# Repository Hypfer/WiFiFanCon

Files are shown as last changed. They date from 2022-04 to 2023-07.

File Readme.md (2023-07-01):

# WiFiFanCon

Control 12V PC Fans via Wi-Fi and [Tasmota](https://github.com/arendst/Tasmota)

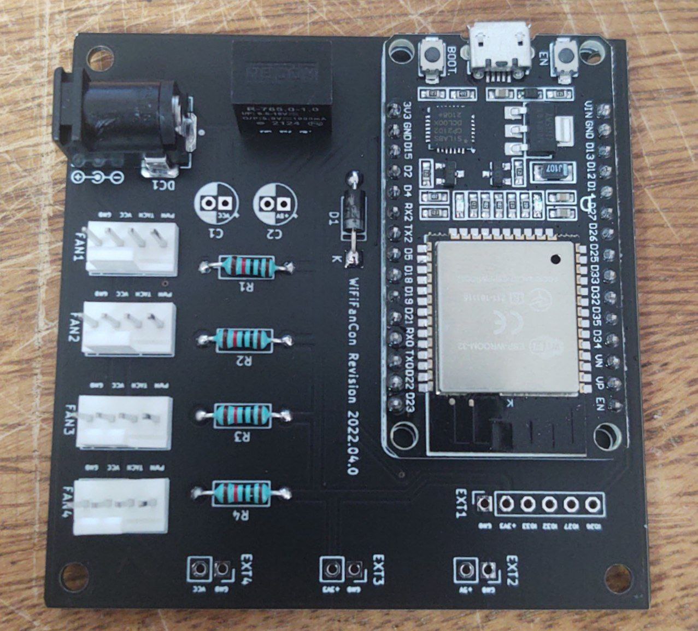
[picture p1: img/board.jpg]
[](./img/board.jpg)
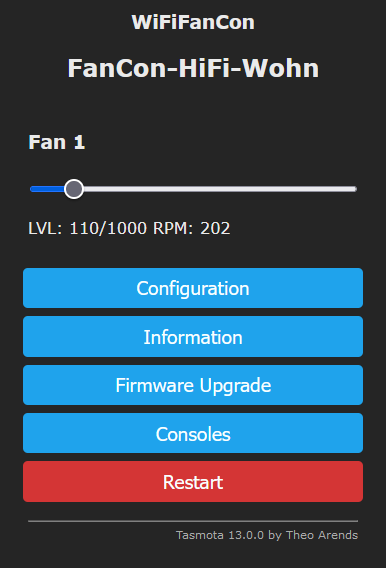
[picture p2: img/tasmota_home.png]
[](./img/board.jpg)

## Features

- Support of up to four 4-Pin PWM 12V PC Fans
- Individual RPM Monitoring for all 4 Fans
- Full control via a Webinterface
- Optional MQTT support with Home Assistant Autodiscovery utilizing [hct](https://github.com/fmtr/hct)
- Extension headers to allow for customization with e.g. additional temperature probes
- Very easy beginner-friendly THT soldering
- Fits snugly into an isolated 45ct junction box

## Where?

Head over to the [./pcb](./pcb) for the pcb.

For the firmware, install [Tasmota](https://github.com/arendst/Tasmota) e.g. using their fancy fully browser-based installer, then check out the [./berry](./berry) folder.

## Why?

I do have quite a few heat-producing devices such as servers or Hi-Fi equipment, which are trapped in whatever
furniture from Ikea barely fit them. This achieves a clean look but also kills the hardware due to insufficient ventilation.

My first solution for this was to add a few very silent 12V Noctua NF-A14 PWM PC Fans and run them at 5V with 33% duty cycle using an Arduino nano.
While that worked just fine, after a year, I've noticed quite a lot of dust buildup on the Fans as well as everything else.

Therefore, I was looking for a way to periodically run the Fans at full speed to blow away whatever dust buildup there might be.
How else would you do that if not via MQTT automated by Home Assistant?

## Pictures?

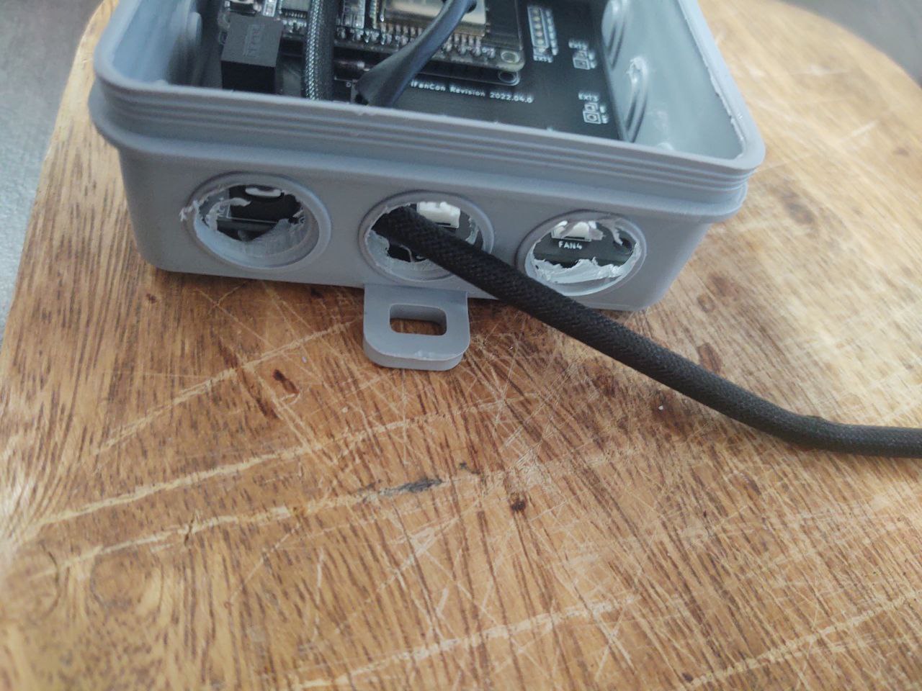
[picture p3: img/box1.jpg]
[](./img/box1.jpg)
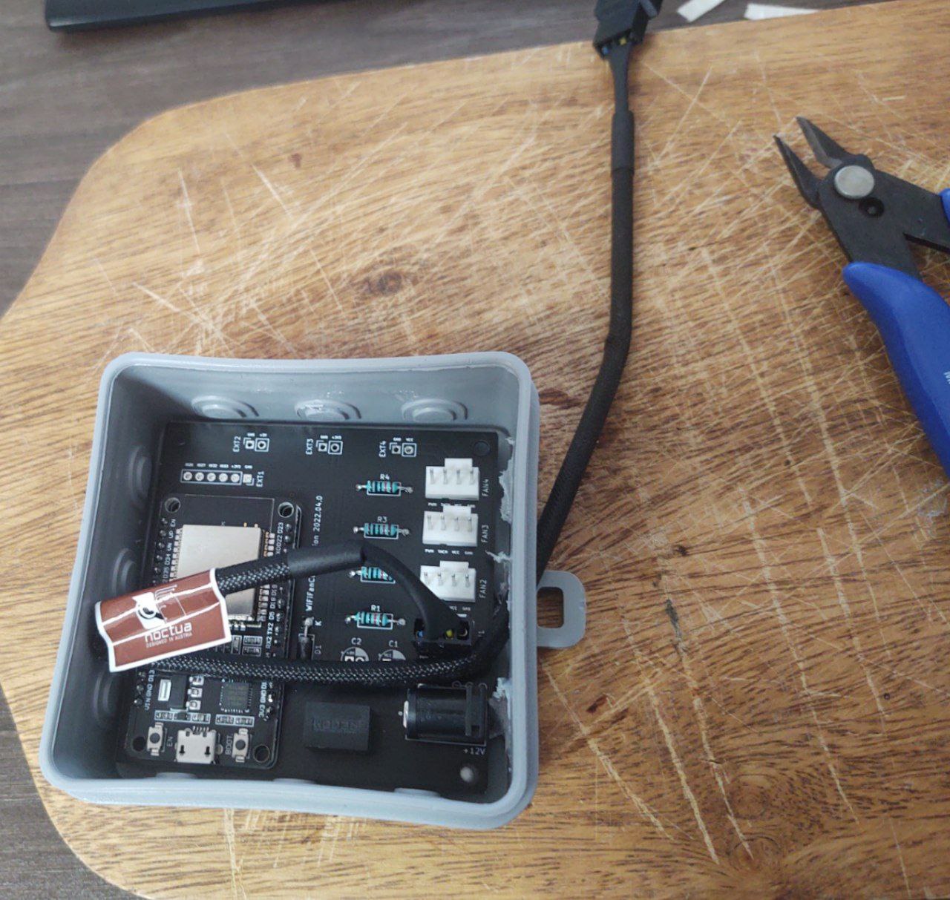
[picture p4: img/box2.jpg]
[](./img/box2.jpg)
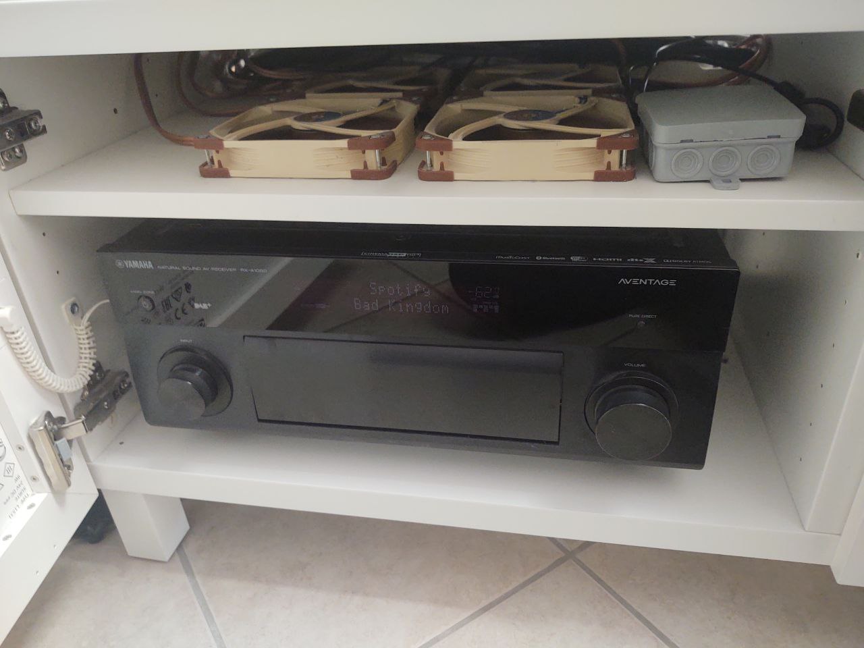
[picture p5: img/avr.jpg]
[](./img/avr.jpg)

## How?

As it turns out, the ESP32 offers everything required for such a project.
It has Wi-Fi, it can do 25kHz PWM with more than 4 channels and it is also capable of monitoring the Fan speed.
Furthermore, as it is available as a full devkit PCB, flashing, soldering and everything else is very easy.

Therefore, I basically just needed to design a PCB that features a DC Jack, some Fan Headers and connects everything in a neat package.
Because it is only 70x70mm in size, it perfectly fits into these dirt-cheap german junction boxes, which you can get for 45ct each.

## Why not use something else?

While there are other projects on GitHub achieving similar things, they didn't really 100% fit my requirements, which are:

- Set Fanspeed to x%
- Don't care about temperature
- Show up in home assistant
- Be very easy to solder

## License

This hardware is licensed under the
[Creative Commons Attribution-ShareAlike 4.0 International License][cc-by-sa].

[CC BY-SA 4.0][cc-by-sa]

The software is licensed under the Apache-2.0 license.

[cc-by-sa]: http://creativecommons.org/licenses/by-sa/4.0/
[cc-by-sa-image]: ./img/cc-by-sa.png

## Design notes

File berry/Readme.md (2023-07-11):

## The software

The software is implemented in the berry language on top of the Tasmota operating system which does all the heavy
lifting, allows for easy Wi-Fi provisioning, general configuration and most importantly stability due to a battle-tested and mature codebase.

### Installation/Setup

After installing [Tasmota](https://github.com/arendst/Tasmota) and having it connected to your Wi-Fi network, a few additional setup steps have to be done:

#### Configure template and Identity

First, in the Tasmota Webinterface of your ESP32, navigate to **Configuration > Other**. There, paste the following template:
```
{"NAME":"WiFiFanCon","GPIO":[0,0,0,0,0,0,0,0,0,0,0,0,1,1,1,1,0,1,1,1,0,1,0,0,0,0,0,0,0,0,0,0,0,0,0,0],"FLAG":0,"BASE":1}
```

Make sure to check the **Activate** checkbox. Also, while you're there, consider setting up the _Device Name_ and _Friendly Name_.
Please note that the code of this project requires you to stick to `[A-Za-z0-9 _-]` for those.
Use of any other characters for those names will likely result in stuff not working correctly.

Click Save and wait for the ESP to reboot.

#### Configure parameters

After it has rebooted successfully, navigate back to the main page and then go to **Consoles > Console** and execute the following commands:

- `PWMFrequency 25000` to set the correct PWM frequency for 12V PC Fans
- `SetOption15 OFF` to prevent Tasmota from treating the PWM as a Light
- `WebSensor1 0` to hide the Counters (an implementation detail) from the Tasmota Webpage
- `PWMRange 1023` to set the PWM range to what is assumed by the code

It's possible that Tasmota will reboot to apply the changes made by some of those commands so make sure to wait for a few seconds between those.
You can always check if they were applied correctly by just running the command without the new desired value:
```
15:36:23.046 CMD: PWMFrequency
15:36:23.053 MQT: stat/tasmota_642EFC/RESULT = {"PWMFrequency":25000}
```

#### Configure GPIOs

Once those parameters are set up, head over to **Configuration > Configure Module** and set up the GPIOs according to your needs.
On the PCB, the four PC fan headers are wired as follows:

- FAN1: PWM GPIO17, Tacho GPIO16
- FAN2: PWM GPIO19, Tacho GPIO18
- FAN3: PWM GPIO22, Tacho GPIO21
- FAN4: PWM GPIO25, Tacho GPIO23

meaning that e.g. GPIO16 in Tasmota would be set up as Counter 1 and GPIO17 in Tasmota would be set up as PWM 1.

**Note**:
If you don't need all four fan headers, don't configure their GPIOs.
The amount of configured PWM GPIOs controls how many Fans will show up in the Web and via MQTT.
Make sure that your IDs configured in Tasmota start at 1 and don't skip any number.
Also, keep in mind that the FAN1 header doesn't strictly have to be PWM/Counter 1 in Tasmota.

#### Upload code

With the GPIOs all set up, navigate to **Consoles > Manage File System** and upload all the .be files from the `src` directory next to this readme.

If you don't need MQTT support then you're done now. Simply reboot the system and enjoy Fan control on the Main Web page.

#### MQTT Setup

If you **do** want MQTT support, there's one final thing you'll need to do beside configuring MQTT Host/Credentials/Parameters in the Tasmota settings.
Head over to the [hct](https://github.com/fmtr/hct) repo, follow the installation instructions, reboot and you're done.

If you connect the WiFiFanCon to Home Assistant via MQTT, don't forget to disable the autoconfigured Counter entities, as they serve no purpose in this setup and will only pollute your `recorder:` component with irrelevant data.

#### Final remarks

If you experience any issues, make sure to check the Log output in the **Consoles > Berry Scripting Console** for error messages etc.

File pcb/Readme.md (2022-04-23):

## The Board

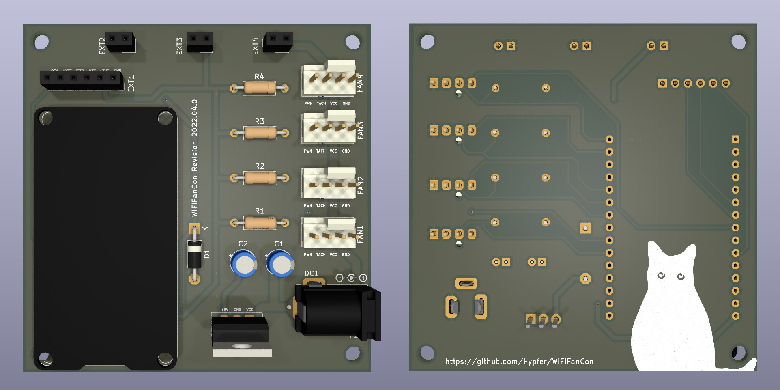
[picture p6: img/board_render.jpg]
[](../img/board_render.jpg)

Gerber files can be found in the [releases section](https://github.com/Hypfer/WiFiFanCon/releases), but you can also just create them yourself using KiCAD 6

## Required parts

To build one of these you will need:

- 1x ESP32 Devkit.

  There are multiple revisions of this. make sure to get the 30-Pin one where the first pin on the left of the USB connector is labelled VIN.

- 4x 10k Resistor

- 4x 4-Pin PC Fan Header

  I used the Molex 47053-1000

- 1x DC Jack

  The board was designed with the CUI PJ-202BH in mind

- 1x 1N5817 Schottky Diode

  To protect your voltage regulator

- 1x Voltage Regulator 12v -> 5v

  I've used the RECOM R-785.0-1.0, which is very efficient and doesn't require any other components

- 0-2x 10uF 16v or similar cap

  Your voltage regulator might need those

Soldering should be straightforward and easy even for beginners.

I recommend the following order:
1. Resistors
2. Schottky
3. ESP32 Devkit
4. (Caps)
5. Fan Headers
6. DC Jack
7. Voltage Regulator

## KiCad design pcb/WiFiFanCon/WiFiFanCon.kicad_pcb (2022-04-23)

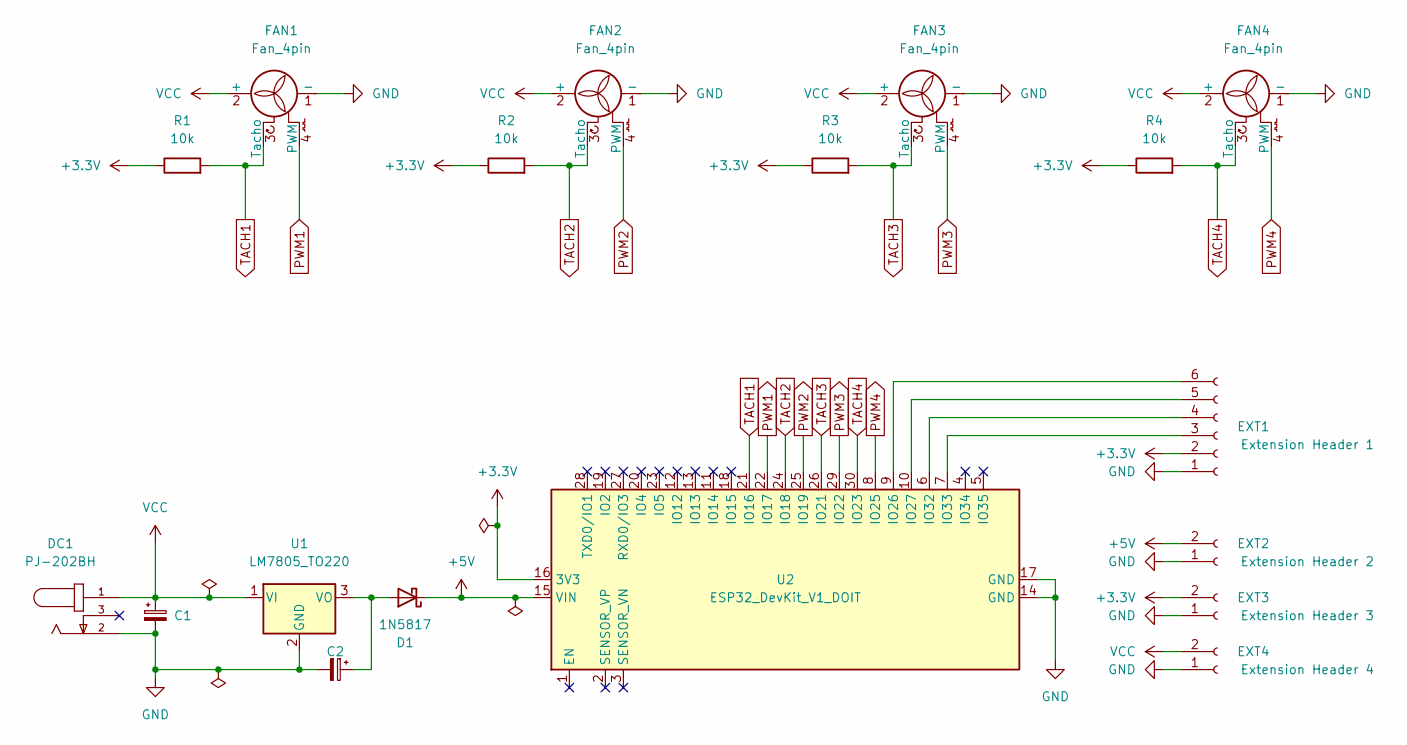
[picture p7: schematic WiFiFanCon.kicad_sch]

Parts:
C1, C2: C_Polarized_Small; CP_Radial_D5.0mm_P2.00mm
D1: 1N5817; D_DO-41_SOD81_P10.16mm_Horizontal
DC1: PJ-202BH; CUI_PJ-202BH; PART_REV 1.02
EXT1: Extension Header 1; PinSocket_1x06_P2.54mm_Vertical
EXT2: Extension Header 2; PinSocket_1x02_P2.54mm_Vertical
EXT3: Extension Header 3; PinSocket_1x02_P2.54mm_Vertical
EXT4: Extension Header 4; PinSocket_1x02_P2.54mm_Vertical
FAN1, FAN2, FAN3, FAN4: Fan_4pin; FanPinHeader_1x04_P2.54mm_Vertical
R1, R2, R3, R4: 10k; R_Axial_DIN0207_L6.3mm_D2.5mm_P10.16mm_Horizontal
U1: LM7805_TO220; TO-220-3_Vertical
U2: ESP32_DevKit_V1_DOIT; esp32_devkit_v1_doit

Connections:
+3V3: EXT1.2, EXT3.2, R1.1, R2.1, R3.1, R4.1, U2.16 (3V3)
+5V: D1.1 (K), EXT2.2, U2.15 (VIN)
GND: C1.2, C2.2, DC1.2, EXT1.1, EXT2.1, EXT3.1, EXT4.1, FAN1.1 (-), FAN2.1 (-), FAN3.1 (-), FAN4.1 (-), U1.2 (GND), U2.14 (GND), U2.17 (GND)
unnamed: C2.1, D1.2 (A), U1.3 (VO)
unnamed: EXT1.3, U2.7 (IO33)
unnamed: EXT1.4, U2.6 (IO32)
unnamed: EXT1.5, U2.10 (IO27)
unnamed: EXT1.6, U2.9 (IO26)
PWM1: FAN1.4 (PWM), U2.22 (IO17)
PWM2: FAN2.4 (PWM), U2.25 (IO19)
PWM3: FAN3.4 (PWM), U2.29 (IO22)
PWM4: FAN4.4 (PWM), U2.8 (IO25)
TACH1: FAN1.3 (Tacho), R1.2, U2.21 (IO16)
TACH2: FAN2.3 (Tacho), R2.2, U2.24 (IO18)
TACH3: FAN3.3 (Tacho), R3.2, U2.26 (IO21)
TACH4: FAN4.3 (Tacho), R4.2, U2.30 (IO23)
VCC: C1.1, DC1.1, EXT4.2, FAN1.2 (+), FAN2.2 (+), FAN3.2 (+), FAN4.2 (+), U1.1 (VI)

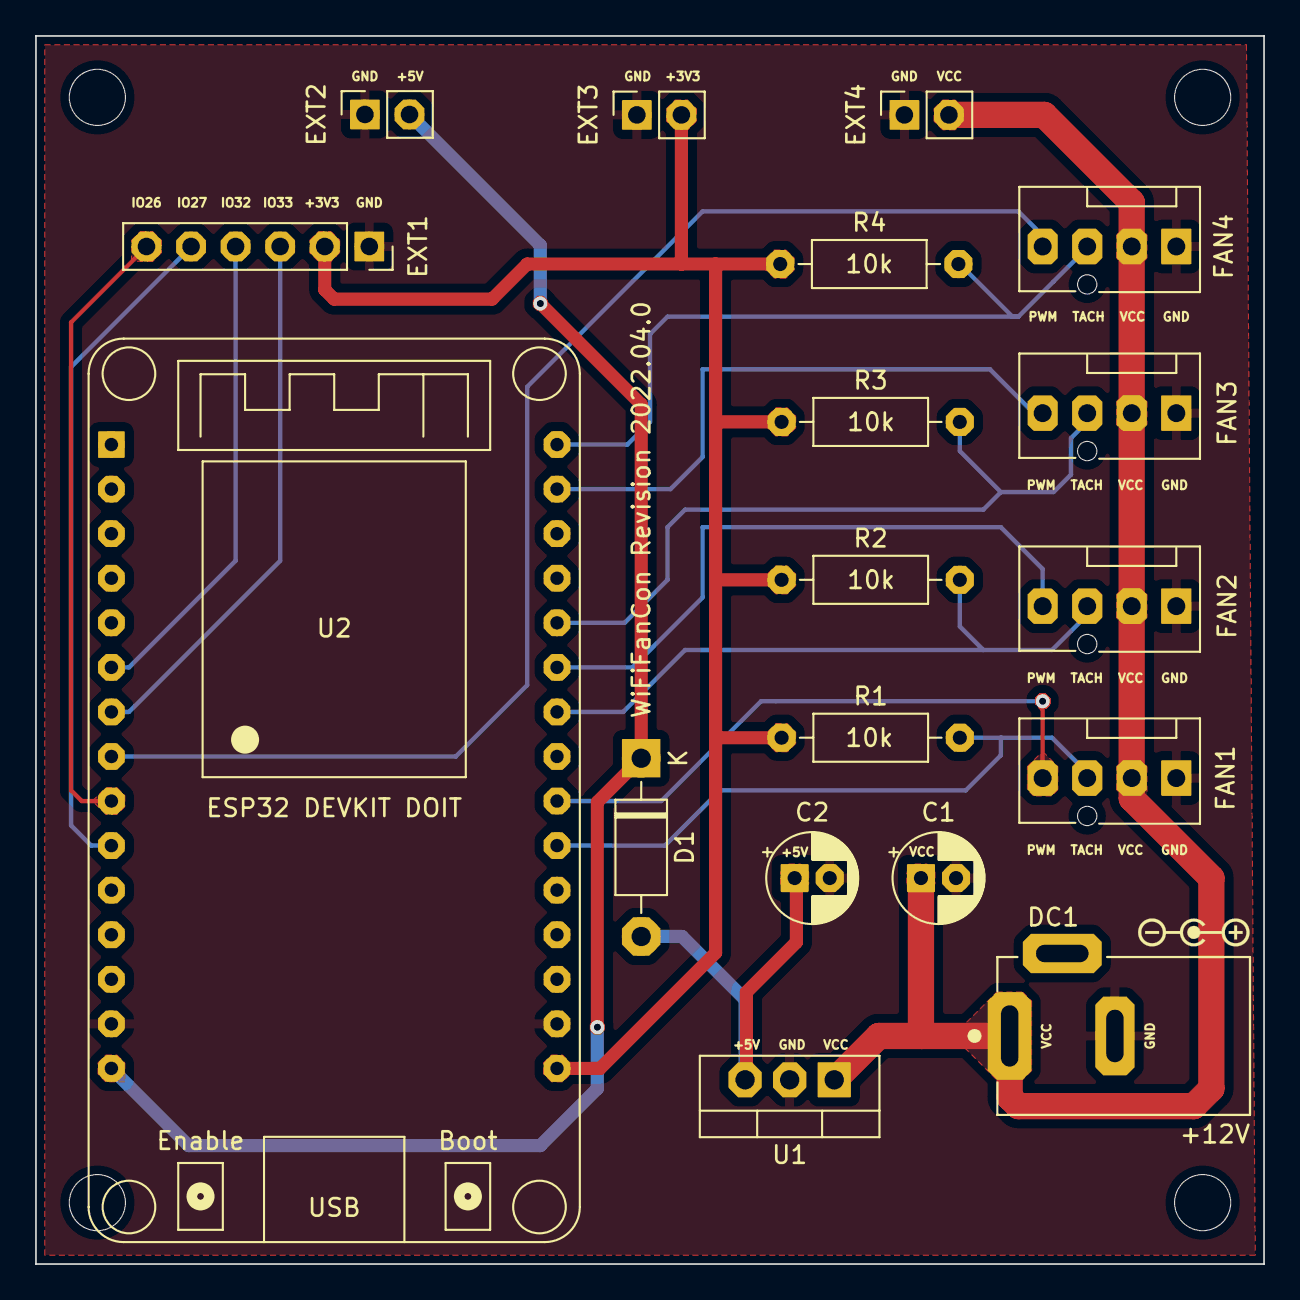
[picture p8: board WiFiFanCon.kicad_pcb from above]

Board: 2 copper layers, 70.0 x 70.0 mm, 18 parts (0 on the bottom side), 17 nets.

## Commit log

2022-04-23 Initial github import
    [WiFiFanCon.kicad_pcb, WiFiFanCon.kicad_sch]
2023-07-11 Fix multi-fan usage
2024-08-25 Calculate RPM more accurately and independently of timer interval (#1)
    - Calculate actual RPM based on time and pulse delta since last update.
    - Eliminates the need to reset the pulse counter after each update..
